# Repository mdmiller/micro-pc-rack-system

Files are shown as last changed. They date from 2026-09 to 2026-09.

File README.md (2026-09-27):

# Micro-PC rack system

3D-printable 19" rack mounting for 1-litre micro PCs. The current design is a 1U
shelf holding two machines side by side, front-loading, with keystone jacks for
console video at the front and a bay for the power bricks at the rear of each tray.

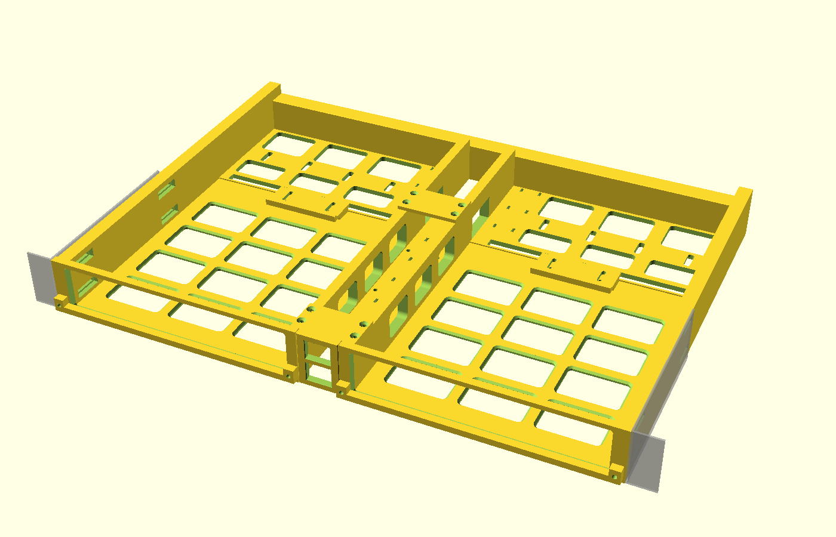
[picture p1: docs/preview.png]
Assembled shelf


**Status:** v3.1 plus the review fixes logged in [DECISIONS.md](docs/DECISIONS.md) (D21–D31),
verified in CAD. Nothing printed yet.

## What it has to do

The requirements the design has to meet. [docs/DECISIONS.md](docs/DECISIONS.md)
explains how each one shaped it.

1. Two 1L micro PCs in 1U of a 19" rack, lying flat, fronts facing out.
2. Mixed models: currently one Lenovo Tiny (179 × 183 × 34.5 mm) and one Dell
   OptiPlex 7060 Micro (182 × 178 × 36 mm).
3. Front keystone jacks for DP/HDMI pass-through — console access without reaching
   behind the rack. Video only; networking comes in from the rear (usually SFP).
4. Each machine removable from the front without disturbing the other.
5. A rear stop to locate each machine.
6. Power bricks and cord management on the shelf itself.
7. Metal, not plastic, in the rack-mounting load path.
8. Front-rail mounting only — no dependence on rear rails. That covers 2-post and
   wall-mount racks, and 4-post racks where the rear is taken up by cabling.
9. Modular toward a future 2U shelf for Minisforum MS-01s, sharing parts.

## Layout

```
cad/rack_1u_micro.scad   parametric OpenSCAD source — the single source of truth
stl/                     binary STLs, pre-oriented for printing; regenerate with build.sh
build.sh                 renders every part from the source
tests/run.sh             interference, clearance and alignment checks
tools/canon_stl.py       makes STL output stable, so git diffs mean real changes
docs/BUILD.md            parts, bill of materials, assembly, servicing
docs/DECISIONS.md        why the design is the way it is
docs/prior-art.md        survey of public designs and what was learned from them
```

## Working on it

```
bash build.sh                                    # all parts
openscad -o stl/tray_left.stl -D 'part="tray_left"' cad/rack_1u_micro.scad
```

Change dimensions in the source, not in the STLs. `build.sh` writes STLs in a canonical
triangle order, so rebuilding unchanged geometry leaves git clean — an STL diff means
the shape really changed.

**OpenSCAD version: 2026.09.18** (a development snapshot). Different versions
tessellate curves differently, so everyone builds with the same one. `build.sh` warns if
yours differs. On macOS, `brew install --cask openscad@snapshot`; elsewhere, see
<https://openscad.org/downloads.html#snapshots>. Snapshots move daily, so don't
`brew upgrade` it on your own: moving the pin means changing `OPENSCAD_VERSION` in
`build.sh` and committing the rebuilt STLs together.

v1 to v3.1 were iterated in Claude Cowork before this repo had any git
history, so the first commit is v3.1 (tagged `v3.1`) and the earlier versions survive
only in [docs/DECISIONS.md](docs/DECISIONS.md). Development continues here with Claude
Code; later delivered designs get their own tags. **Run
`bash tests/run.sh` after changing any parameter** — it checks every part pair on
both sides for collisions, that each machine still slides out, that screw holes
still line up, and that each part prints in its exported orientation with no overhang
beyond the known bridges and the features listed as needing support.

Questions and test-fit results are best as GitHub issues, one per topic, with photos
where relevant.

## Open items

- [ ] Caliper-check the steel bracket before printing both trays: the 23.8 mm hole-row
      spacing (`brk_row_dz`), and the bend-to-first-hole distance, which was never on the
      drawing (`ear_c0` assumes ~15 mm; the ±8 mm slots absorb small errors).
- [ ] Print one tray first and test-fit both machines.
- [ ] Watch temperatures for the first few weeks — see the thermal note in
      DECISIONS.md.
- [ ] Choose a keystone coupler per machine: slim-head HDMI or mini-DP (standard-head
      plugs don't fit; see BUILD.md and D26).
- [ ] Measure each machine's rubber-foot positions, so the floor vents can leave solid
      runners under them (#15).
- [ ] Get the MS-01 power adapter dimensions, then design the 2U shelf.

## Licence

© 2026 Matt Miller and contributors. Everything in this repo — CAD source, STLs,
scripts and docs — is licensed under
[CC BY-NC-SA 4.0](https://creativecommons.org/licenses/by-nc-sa/4.0/); full text in
[LICENSE](LICENSE). In short: print it, use it and remix it freely, as long as you
credit this project, don't use it commercially (that includes selling prints), and
share your remixes under the same licence. For anything commercial, open an issue
and ask.

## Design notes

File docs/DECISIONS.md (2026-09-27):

# Decision log

How the design got to where it is. Most entries follow the same shape: what was
decided, why, and what was rejected. Dates are when the decision was made.

v2 predates the power-brick requirement; v3 incorporates it. Mistakes made along
the way are noted where they happened and collected under Corrections at the end.

---

## Timeline

| Date | Event |
|---|---|
| 2026-09-19 | Brief: 1U shelf, two micro PCs, front keystone for video. v1 drafted internally and rejected; v2 delivered. |
| 2026-09-19 | Mixed Lenovo + Dell confirmed. Survey of public designs. |
| 2026-09-20 | Structural analysis, print orientation, steel ears, front serviceability. Power bricks raised as a hard requirement. Front-rail-only mounting set as a constraint. MS-01 modularity raised. |
| 2026-09-20 | Steel bracket drawing received; v3 designed, verified and shared. |
| 2026-09-20 | Second prior-art pass; the closest public design examined in detail. |
| 2026-09-21 | Repo created. Verification found four defects in v3's front lip; fixed in v3.1 and a test suite added. |
| 2026-09-21 | First git commit, at v3.1. Everything up to here was iterated in Claude Cowork sessions; from this point the work continues in Claude Code, with history in git. |
| 2026-09-21 | Independent review of v3.1 (Temple Keller). Brick bay inner tab found floating (D21); ear nut channels found impossible to load (D22); rear stop redesigned and a cable floor added (D23); fastener lengths, keystone clearance and assembly order corrected (D24). |
| 2026-09-21 | OpenSCAD pinned to 2026.09.18 (D25). |
| 2026-09-21 | Rear video plug clearance: slim HDMI or mini-DP, flange relief, cable floor moved back (D26). |
| 2026-09-21 | Keystone panel and brick bay tabs braced (D27). |
| 2026-09-21 | Rack opening measured at 450.85 mm; keystone column narrowed to 33 mm (D28). |
| 2026-09-22 | Ear bolts: square nut, no washer (D29). |
| 2026-09-22 | Printability fixes from the H2D review (D30). |
| 2026-09-22 | Tests check each part for unsupported overhangs in print orientation (D31). |
| 2026-09-22 | Docs cleanup: stale statements corrected, preview re-rendered. |
| 2026-09-25 | Both bricks calipered, smaller than D15 assumed in every axis; strap row moved so it holds them (D33). |
| 2026-09-23 | Rear stop reaches the Dell, stiffer front lip, chamfered floor vents (D32). |
| 2026-09-26 | Tray and brick bay print as one part, with a glued rear beam across both; centre sag from ~11 mm to ~2.9 (D34). |

---

## Geometry and fit

### D1 — Split the 19" shelf into printable parts
A 482.6 mm panel doesn't fit any consumer bed. Two trays joined at a centre keystone
module. v1 put an 8 mm screw boss across the seam, pushing each tray to 219 mm —
too close to a 220 mm bed — and was rejected before delivery. v2 moved to a top flange
screwed into the inner walls (215 mm trays). v3 is 201 mm (203 in v3.1), because the steel ears
(D8) remove the printed ear entirely.
*Since D34 each tray includes its brick bay and is 211 × 316 mm; the 220 mm bed goal is dropped.*

### D2 — PC faces flush in full-width openings
Each bay's front opening is the full bay width, so power buttons, front USB and jacks
are all reachable. **Correction:** v2's notes claimed the case front butted against
the panel. It doesn't — an interference test showed the pull-out corridor is clear,
so v2 had no front stop at all. That turned out to make front loading (D11) almost free.

### D3 — Mixed machines share one envelope
Bays are sized for the larger of the two in every axis (182 × 183 × 36). Only the
rear stop varies by model (a 34.5 mm Lenovo variant existed until D23 made one stop fit all). Do **not** re-render a
tray with a different `dev_h` or `dev_d`: `dev_h` sets the inner wall height the
keystone flange and tie plate sit on, and `dev_d` moves the tie-plate screws. `dev_w`
per tray is safe, at the cost of a 2 mm asymmetry in the front frame.

### D4 — Keystones are video only; stacked vertically
Two jacks, one per machine, for DP/HDMI couplers. Networking stays at the rear.
In v3 the jacks are rotated 90° and stacked: the thicker outer walls (D9) cost 12 mm
of width that had to come from the centre column, and side-by-side jacks would have
left 2.6 mm edges. Stacked needs ~29 mm; the column is 40 in v3, 36 in v3.1 (D19) and 33 after D28. Rear-plug clearance for this layout: D26.

---

## Structure

### D5 — PETG / ASA, not PLA
The concern is creep in a warm rack over months, not strength (see D6).

### D6 — The cantilever is not the problem; the ear screws are
Front-rail-only mounting with the bricks at the far end looked like the worst case,
so it was calculated rather than guessed. Per tray: PC 1.30 kg at 97 mm, brick
0.55 kg at 285 mm, structure 0.50 kg at 150 mm.

| Quantity | Result |
|---|---|
| Root bending stress | 0.73 MPa (≈3.6% of PETG layer-bond strength) |
| Tip deflection, short term | 0.18 mm |
| Tip deflection, creep-adjusted (E = 900 MPa) | 0.40 mm |
| Load per top rack screw, 1U ear | 111 N (11 kg) |
| Same, with a 2U-tall ear | 39 N |

The tray is a 39 mm-deep U-channel; depth beats length. **Correction:** an earlier
note had overstated the cantilever risk. The real concentration is the rack screw
pulling through a 5 mm strip of plastic beside a 7.2 mm slot, in the layer-weak
direction.

### D7 — Print orientation: floor-down, not face-down
Several public designs print face-down so the ear's bending stress runs along the
extrusions instead of across layer bonds (critical section ≈95 mm² of pure layer
adhesion when printed floor-down). That's correct for printed ears — but with steel
ears (D8) the printed part has no such critical section, and face-down would mean a
206 mm-tall print standing on a mostly-open front frame. So: floor-down, which is the
easier print.

### D8 — Steel rack ears
Penn-Elcom R1206/1U or equivalent: 1.5 mm steel, 43.8 × 20 mm leg, 139.4 mm web.
From the drawing: four Ø4.8 holes, columns 110 mm apart, rows 23.8 mm apart, lower
row 9.4 mm above the bottom edge (9.4 + 23.8 + 10.6 = 43.8, which is how the reading
was confirmed). Removes plastic from the load path and resolves D7.

### D9 — Continuous nut channels, not holes or inserts
The drawing doesn't give the bend-to-first-hole distance, so fixed holes risked
missing. Heat-set inserts can't be slotted, and there's no room inside the bay for
loose nuts. Each outer wall instead carries two M4 nut channels running front to back.
Consequences: outer wall 11 mm; M4 × 8 **button head** (a longer bolt bottoms out,
a socket head fouls the rail); body 442 mm, leaving 2.5 mm per side in a 450 mm
opening. **Correction (D28):** that counted the steel but not the bolt heads. Verified: an M4 hex nut seats in the channel and the bolt clears.
**Superseded by D22:** the nuts could never be loaded into the channels.

### D10 — Centre tie at front and rear
Keystone module (front) and tie plate (rear) both bolt across the two inner walls.
*D34 adds a rear beam glued in across both trays.*
Field evidence later confirmed this matters: users of the closest public design found
it needs support in the centre once racked (see prior-art.md).

---

## Serviceability and retention

### D11 — Front loading
In a tightly packed rack, pulling the whole shelf to service one machine is not
acceptable. Since the corridor was already clear (D2), v3 only needed a front stop.

**Servicing procedure (2026-09-21, issue #7):** a machine's rear cables are unplugged
from behind the rack before it slides out the front. Pulling it out with cables still
attached would need ~200 mm of free slack on each rear cable. Behind each machine, the
bay has only ~8–27 mm of free depth left after the rear plugs and the brick, and
building in room for service loops would lengthen the shelf. The machines have no
hot-swappable parts, so a rare, tight reach from behind was judged the simpler
trade-off.

### D12 — Front lip instead of clips
Per-bay clips were planned, but there's no structural material inside the full-width
opening to anchor them. The lip spans the opening and screws into the two wall strips
either side, covering the bottom 5 mm of each case front (bezel on both models).
Two screws, lip off, machine slides out. Redesigned in v3.1 after defects were found (D19).

### D13 — Rear stop is set once
Slotted for ±7 mm (172–186 mm device depth), with a 45° self-supporting hook over the
case's rear top edge to stop lift. It's positioned at build time, not a service item.
**Hook replaced by a low curb in D23.**
*The ±7 mm / 172–186 mm figures were stale; the stop reached 179.5–190.5 mm, which missed
the 178 mm Dell. Moved in D32 to 175.5–186.5 mm.*

---

## Power bricks

### D14 — Bricks on the same shelf, behind the PCs
Not a separate U: the point of the design is density, and a U spent on power bricks
is a U lost. The shelf mounts on the front rails only (requirement 8), so it grows
rearward in a bolt-on bay (part of the tray since D34) rather than reaching for rear rails. D6 showed the extra
moment is harmless. On a 4-post rack, rear support is an available fallback, but
nothing in the design needs it.

### D15 — Bricks crosswise
Designed to the Lenovo brick (112 × 51 × 35 mm plus ~70 mm of plug and boot) and the
Dell 90 W (130 × 70 × 28). A 130 W Dell adapter exists but isn't needed. Laid crosswise
with mains ends outboard, the pair uses ~372 mm of the width and a 90 mm-deep bay;
lengthwise would have needed ~190 mm of depth. Overall depth ~316 mm. The Lenovo's
35 mm thickness leaves 6.5 mm of headroom in the U, so straps pass under and around,
never over. DC leads run forward through the 36 mm centre gap between the two bays.
*Corrected since: the bay floor is 4 mm, so headroom is ~5.5 mm, and a strap does pass
over the brick (D24). DC leads only run forward to each machine's own jack; the centre
gap carries the video leads (D23). Both bricks were calipered on 2026-09-25 and are
smaller in every axis: Lenovo 65 W slim 107 × 46 × 29, Dell 90 W 128 × 66 × 23. Headroom
over the Lenovo is ~11 mm, not ~5.5, and the pair uses ~365 mm of width (D33).*

### D16 — Thermal risk, accepted and partly de-risked
Both machines exhaust rearward toward the bricks. Mitigations: ~29 mm plenum, vented
floor, open rear, and bays that unbolt so the bricks can move to their own U without
touching anything else (*no longer: the bays are part of the trays, D34*). Later evidence: the closest public design puts two PCs and
both bricks in 1U with the bricks directly behind, printed in PLA+, and months of
use by several builders produced no heat or warping complaints. Still worth watching.
*The plenum is now ~40 mm: the bricks sit behind the 25 mm kept clear for the machines'
rear plugs.*

Design assumptions: machines that run mostly idle rather than at sustained full
load, in a rack with its own forced ventilation and an interior at or below about
40 °C (100 °F). Under those assumptions, going to 2U for thermal reasons was rejected
as a waste of rack space, and the shelf has no fan of its own. If your rack is
hotter, unventilated, or the machines run flat out, revisit this: the open rear
leaves room to add a fan.

---

## Scope and ecosystem

### D17 — 1U micro shelf now; 2U MS-01 shelf later, sharing parts
The MS-01 is 196 × 189 × 48 mm with a 180 W adapter. At 48 mm it cannot fit in 1U,
so it gets a 2U shelf that reuses the ears, keystone module, brick bays and rear
stops. Only the tray changes.

### D18 — Build our own rather than remix the closest public design
Nothing public met all the requirements (see prior-art.md). The closest is
Turaj Pilehvar's Dell Micro 1U mount. Remixing was rejected because: it is STL-only
and the author has confirmed no CAD exists; another user tried importing the STLs
into Fusion 360 for a remix and gave up to redraw from scratch; and changing the bay
for a Lenovo plus adding keystones would alter exactly the geometry that had been
field-tested. What transferred instead was information (D10, D16).

### D20 — Licence: CC BY-NC-SA 4.0 (2026-09-21)
The goal: anyone can print, use and remix the design, with attribution, but not
commercially. CC BY-NC-SA 4.0 does that, and ShareAlike keeps remixes under the same
terms. One licence covers the whole repo, scripts included — Creative Commons advises
against CC licences for software, but the scripts here are small helpers tied to the
design, and splitting licences wasn't worth the complexity. CC BY-NC (no ShareAlike)
was the alternative considered. The `CC-BY-4.0` note in the v3 source header was
added during drafting without anyone deciding it, and is replaced.

---

## Corrections

### D19 — v3.1: front lip defects, found in verification (2026-09-21)
Found while setting up this repo, not by printing. Chasing zero-area triangles in
the exported front lip led to four real defects in v3 as shipped:

1. **The right-hand lip didn't line up.** The lip's holes weren't symmetric, but the
   same part was placed on both trays without mirroring. On the right tray the holes
   missed the pilots by 2.5 mm. The v3 checks only ever tested the left side.
2. **The inner hole broke out of the lip's end** — its centre sat 1 mm from the edge.
3. **The countersunk head was wider than the lip:** a 6.6 mm head on a 5 mm strip,
   leaving 0.8 mm of plastic around the hole.
4. **The outer pilot ran ~1 mm into the lower nut channel.** Two voids touching,
   which no solid-against-solid test can see.

Fixes:
- Symmetric lip with 11 mm end tabs sitting over the two wall strips (never over a
  PC face), M3 pan heads instead of countersunk. One part fits either tray.
- Outer pilot shortened to stop 1 mm short of the nut channel.
- Inner walls widened 6 → 8 mm, taken from the keystone column (40 → 36; the stacked
  jacks need ~29). Overall width unchanged at 442 mm. Every screw into the inner
  walls — keystone flange, tie plate, lip, brick bay — now gets 4 mm of edge
  distance instead of 3, and no countersink breaks out of a flange edge.
- Countersink cones everywhere now stop at the clearance diameter rather than a
  zero-width point.

The checks that would have caught all four are now in `tests/run.sh`: every part
pair on both sides, rods down each lip hole *as placed*, void-against-void tests,
and nut and bolt fit. The alignment tests were confirmed to fail both on the
shipped v3 and on a deliberately broken lip.

**The v3 files shared before this repo existed have these defects. Use this repo.**

### D21 — Brick bay inner mounting tab floated above the floor (2026-09-21)
*The tabs are gone since D34.*
Found by counting connected solids in the exported mesh: `brick_bay` was two
separate bodies. Both front mounting tabs started at z = 8. The outer one overlaps
the outer lip beneath it (12 mm tall), so it was fused. The inner edge is the open
cable-run side and has no lip, so the inner tab hung 4 mm above the 4 mm floor with
nothing joining them. It sliced as an unsupported island, and it carries one of the
two bolts that hold each bay to its tray.

Fix: both tabs now run from the floor (z 0–32). The outer tab is unchanged in the
union, because it already sat inside the lip.

Why the checks missed it: every existing test is an intersection between two parts,
and a part that falls apart into two bodies doesn't collide with anything. New test
`bb_tab_rooted_L` requires the space under the inner tab to be solid; it fails on
v3.1 and passes now.

### D22 — Ear nut channels couldn't be loaded; replaced with per-bolt pockets (2026-09-21)
*Washer and hex nut replaced by a square nut in D29.*
D9's channels were sealed at both ends. They run y 8–165 inside a wall that runs
6–206, so the "slide the nuts in from the rear" step had 41 mm of solid wall in the way.
The only opening was the 4.8 mm bolt slot on the outside face. A 7 mm nut passes that
only lying flat, and the 4 mm-deep pocket has no room to stand it up. Sweeping the
`m4_nut_fits` nut out of its seat towards the bay, the outside, the rear and the front
hits wall every time. Each channel roof was also a 157 mm unsupported bridge when
printed floor-down.

Fix: four pockets per tray, one per bracket hole, each open to the bay. A washer and
nut go in from inside before the machine does; the bolt comes in from outside through
a slot that keeps ±8 mm of fore-aft travel (`ear_c0`, `ear_travel`), so the
bracket's column position still needn't be exact. The longest roof is now a 25.6 mm
bridge supported at both ends.

- **Washer:** it spreads the clamp load off the strips of skin beside the slot. The
  old nut bore on two 1.1 mm strips.
- **No anti-rotation:** a stepped pocket that would stop the nut spinning was tried and
  dropped. A 9 mm washer can't pass a 7.3 mm nut opening or be turned upright inside
  one, so the pocket is washer-sized and the nut is held while tightening.
- **Bolts:** now M4 × 12. Through 1.5 mm steel, 6.5 mm skin and a 0.8 mm washer, the
  tip lands flush with the nut face, 0.5 mm short of the bay.
- **Lip pilot:** the outer lip pilot keeps D19's rule and stops 1 mm short of the new
  front pockets.

Why the checks missed it: `m4_nut_fits` placed a nut in its final position and
confirmed it fit. It never asked how the nut got there. Replaced by:
- `m4_hw_seated`: bolt, washer and nut at both ends of travel in all four holes.
- `m4_hw_insertable`: washer and nut swept in from the bay.
- `m4_past_travel`: the same hardware 4 mm past the end of travel must hit wall, which
  proves the other two can fail.

### D23 — Open rear, cable floor, zip-tie anchors (2026-09-21)
**Rear stop.** The hook's web was a solid plate 64 mm wide and 33 mm tall, flush
against the middle third of each machine's rear face (about 32% of it), where the
ports and exhaust are. That conflicts with requirement 3's rear video cables and with
D16's airflow, and it depended on `dev_h`, hence the Lenovo variant. The stop is now
a curb that touches only the bottom `stop_h` (8 mm) of the rear face. One part fits
every machine, the rear stays open for any port layout, and the Lenovo variant is
gone. It gives up the hook's lift restraint; the U above and the front lip bound that.

**Cable floor.** Requirement 6 calls cord management imperative, but the video leads
had no supported route to the keystones:
- the inner wall behind each machine is solid;
- the tie plate leaves ~2.5 mm over the top of the wall;
- the centre channel between the trays had nothing under it.

A new `cable_floor` part spans the channel on a 6 × 4 mm ledge added to each inner
wall and screws down from above. Zip ties pass through slot pairs into the 4 mm gap
beneath, so nothing hangs below the shelf. It also ties the bottoms of the two trays
together; that stiffening hasn't been quantified. The route for each video lead is:
machine's rear → brick bay → centre gap → cable floor → keystone. D15's "DC leads run
forward through the centre gap" was a slip: DC leads only go forward to each
machine's own jack.

**Brick bay.** Zip-tie anchors along the inboard edge: slot pairs joined by an
underside groove, so the strap sits flush with the bottom face.

New tests:
- `tray_cf`, `keystone_cf`, `tie_cf`, `bricks_cf`: no collisions.
- `cf_holes`: screw cores pass the floor into the ledge pilots without bottoming out.
- `ziptie_void`: the gap under the floor is clear.
- `rear_face_open_L`: nothing touches the rear face above the curb.
- `stop_meets_face_L`: the curb does meet the face.

### D24 — Fastener lengths, keystone clearance, assembly order, supports (2026-09-21)
Found by working through every screw (reach, length, engagement), every assembly step
(possible in this order, in a rack?) and every part (printable as exported?):

- **Rear-stop screws broke through.** The BOM's M3 × 10, through the 3 mm foot into
  6 mm of pad and floor, stuck 1 mm out of the underside into the U below. Now M3 × 8,
  and the pilot starts at z = 0.6 so the flat tip clears the pilot bottom instead of
  meeting it. The test models the screw 0.5 mm long to keep that margin, which catches
  both the old pilot and the old screw.
- **The keystone panel had zero clearance:** 36.0 mm in a 36.0 mm gap between the tray
  panels. Now 35.4 mm (`ks_clr` = 0.3 per side, the same as the cable floor).
- **Assembly order.** Tightening the ear bolts and setting the rear stops after racking
  isn't possible with the U above populated: the nuts and stop screws are reached from
  above, and the bolt heads sit between the bracket and the rail. All of that, plus
  fitting the couplers and plugging in the video leads, now happens on the bench. The
  couplers go in first, with the panel backed up, because the installed panel hangs
  from a 36 × 3 mm joint loaded across the print layers. The shelf is racked empty and
  the machines slide in from the front.
- **Supports.** The strip above each PC opening is a 184 mm unsupported span when
  printed floor-down, so the trays need supports there. "No supports" was wrong.
  *Since then (D31, 2026-09-22): slicer settings, including how to support, are left to
  the 3MF built from this geometry. BUILD.md only says which features need support, and
  `tests/run.sh` checks that list. "Supports from the build plate are enough" was wrong:
  the support stands on the panel's own lower strip.*
- **Headroom.** The bay floor is 4 mm, not 3, so the Lenovo brick gets about 5.5 mm of
  headroom, not 6.5. A velcro strap does pass over the brick: it has to, to hold it.
  That corrects D15.
  *Since measured (D33): the Lenovo brick is 29 mm thick, so headroom is ~11 mm.*

New tests:
- `stop_screws_L` / `_R`: fail on v3.1, pass now.
- `keystone_side_clear`: fails on v3.1 with 131 mm³ of overlap, passes now.
- `cf_holes`: now uses 2.6 mm cores, so a tip that runs through a pilot's skin shows up
  above the 2 mm³ threshold.

### D25 — Pin the OpenSCAD version (2026-09-21)
Different OpenSCAD versions tessellate curves differently. `canon_stl.py` only makes
identical *triangles* byte-identical, so two contributors on different versions each
rewrite every curved STL on every build. The review PRs (D21–D24) were built on
2026.06.12, and three STLs then changed when rebuilt on 2026.09.18, with no change in
shape. Pinned to 2026.09.18, the version the owner already had and the current
Homebrew `openscad@snapshot`. `build.sh` warns on a mismatch rather than failing,
because a mismatched build is still geometrically correct, just noisy in git. The
2021.01 stable release was never in use here.

### D26 — Rear video plug clearance (2026-09-21, issue #6)
The rotated, stacked jacks (D4) put each rear plug on its long edge, 18.8 mm apart,
between the keystone flange above (underside at z = 39, back to y = 36) and the
cable floor below. Plugs were modelled as blocks at two coupler depths (rear face 24
and 32 mm behind the panel front):

- **Standard HDMI or DP heads (~21 × 11 × 40 mm)** collide with each other, the
  flange and the cable floor under every small change considered. The two plugs alone
  overlap by ~1000 mm³.
- **Slim HDMI heads (16 × 6.6 × 14 mm)** missed by ~0.2 mm per side at the flange and
  hit the cable floor at the deeper coupler depth.
- **Mini-DP** is smaller still.

Three ways to make 2 × slim HDMI fit were compared:

| Option | Upper plug to flange | Plug to plug | Cost |
|---|---|---|---|
| `ks_gap` 4 → 3 | 0.3 mm | 1.8 mm | halves the full-thickness plastic between the jacks (2 → 1 mm) |
| **1 mm relief in the flange underside** | 0.8 mm | 2.8 mm | flange 2 mm thick instead of 3 over a 9 mm-wide strip |
| Move the flange back | — | — | restructures the keystone module for no extra gain |

Chosen: the relief (`ks_relief_d` = 1.0, `ks_relief_w` = 9). It starts behind the
panel at y = 8.8, so the panel-to-flange joint is untouched. `cf_y0` goes from 44 to 50
so the lower plug's head clears the floor. The first cable-floor screw pair moves
54 → 58 to keep its edge distance.

**Supported cables:**
- 2 × slim HDMI (passive; active RedMere cables may not like a passive coupler);
- 2 × mini-DP;
- one of each;
- mini-DP upper with standard HDMI lower, provided `cf_y0` goes to ~85–90.

Standard-head cables in both jacks would need the jacks turned upright and the flange
cut away over them. That's a different layout, not taken.

Tests: `plug_vs_keystone`, `plug_vs_cf` and `plug_vs_plug` check both jacks at both
coupler depths. The first two failed before this change. `flange_over_relief` checks
that 2 mm of flange remains.

### D27 — Brace the keystone panel and the brick bay tabs (2026-09-21, issue #11)
*The brick bay tabs and their braces are gone since D34.*
Two parts behave like vertical posts loaded across their print layers. The numbers
are hand calculations with rounded loads; the ratios are what matter.

**Keystone panel.** It hangs from a 35.4 × 3 mm joint with the flange. The module
prints panel-down, so that joint is a layer boundary. A 30 N push on the lower jack,
from plugging a monitor into the front, gives ~16 MPa there, repeated at every plug-in.
Two 12 mm braces between the panel back and the flange underside fix it. They sit in
the 3.7 mm strips at the panel edges, clear of the jacks' latch travel. The composite
section takes the same push to ~2.2 MPa, about 7× less, and the braces print as 45°
fins.

**Brick bay tabs.** The bay hangs from two bolts at z = 20.
- **Inner tab (8 × 4 mm).** At rest it sees ~6.5 MPa at its root; a 50 N handling load
  gives ~38 MPa. An 11 mm brace behind it, topping out below the bolt head, moves the
  weakest section up to the brace top, where the same load gives ~12 MPa.
- **Outer tab (above the 12 mm lip).** A 50 N load gives ~14 MPa; a 4.5 mm brace takes
  it to ~6 MPa.

The bay braces sit in the front ~25 mm that is already kept clear for the machines'
rear plugs.

**Not braced:**
- the tray wall-to-floor corners inside the bays (~1 mm PC clearance, no room);
- the tray's front posts (backed by the full-length walls).

Tests: `ks_braces_present` and `bb_braces_present_L` fail before this change and pass
now. `ks_latch_room` keeps the jacks plus 2.5 mm of latch travel clear; widening the
braces to 6 mm makes it fail. `bb_driver_clear_L` keeps the M3 heads and the screwdriver
path along y clear.

### D28 — Clearance in the rack opening (2026-09-21, issue #5)
With the steel ears fitted, the shelf is widest across the M4 button heads: body
+ 2 × 1.5 mm web + 2 × 2.2 mm head. At 442 mm that was 449.4 mm. The rack's clear width
between the front rails was measured at 450.85 mm (17¾", two tapes), leaving 0.7 mm
per side. That's about a tape measure's own accuracy, before print tolerance or web
flatness. Standard rack equipment leaves about 3 mm per side.

Four ways to take 3 mm out were run against the full test suite:

| Change | Result |
|---|---|
| **Keystone column 36 → 33** | all checks pass |
| Column 34, bay fit 1 → 0.75 | machines graze the openings sliding out (`pullout`) |
| Inner walls 8 → 7, bay fit 0.75 | `pullout` and `lip_clear_of_face` fail |
| Column 34, inner walls 7.5 | `lip_clear_of_face` fails |

Chosen: `key_w` = 33, giving a 439 mm body, 446.4 mm across the bolt heads and
**2.2 mm per side**. The keystone panel, tie plate and cable floor are all derived from
`key_w` and follow. The cost is latch access: the gap between each keystone brace (D27)
and the jack body shrinks from ~4.3 to ~2.85 mm. That still covers the 2.5 mm of latch
travel `ks_latch_room` reserves, and couplers are fitted once on the bench. 33 is the
floor: at 32 the braces cut into the latch clearance.

`rack_open` and `rack_margin` now live in the source. The new test
`rack_width_margin` models the heads at every bolt and fails if they come within
2 mm of the rails; it fails at 36 (461 mm³ outside the margin) and passes at 33.

### D29 — Ear bolts: square nut, no washer (2026-09-22, issue #15)
D22's pocket was sized for a 9 mm washer, which made it taller than the hex nut's
8.1 mm corners. That caused two problems:
- The nut spun freely. The only way to hold it was a fingertip; a spanner can't get
  around a nut inside a 9.3 mm pocket.
- The pocket had 0.3 mm of clearance over the washer. Layer quantisation and roof sag
  (#15) could close that up, so the washer might not go in at all.

A square nut in the same washer pocket doesn't fully fix it. Its 9.9 mm diagonal lets
it turn 23–37° before jamming corner-first into printed plastic, depending on the
printed pocket height. And the window between "washer won't fit" and "nut spins
freely" is only ~0.7 mm.

Chosen: **square M4 nut (DIN 557), no washer, pocket sized to the nut** (7.4 mm tall,
`nut_clr` 0.4). In that pocket the nut can turn about 2.5° before it locks, and it
still slides fore-aft with the ±8 mm travel.

**What dropping the washer costs.** Once the 4.5 mm slot band is taken out, the nut's
face bears on less plastic:

| Nut bearing on plastic | Area | Stress at ~0.5 N·m |
|---|---|---|
| washer (D22) | ~25 mm² | — |
| **square nut** | **~17.5 mm²** | ~36 MPa |
| hex nut | ~11.9 mm² | ~52 MPa |

Among the no-washer options the square nut is clearly better: the hex nut is already
around PETG's crush strength at snug. Dropping the washer also frees 0.8 mm, so the
solid skin goes from 6.5 to 7.3 mm, which helps pull-through and the slot edges' bearing
against the bolt. M4 × 12 still lands flush with the nut face, 0.5 mm short of the bay.

**Assembly note.** BUILD.md now says "snug, not hard". The joint's load is the bolt
shanks bearing on the slot edges, not clamp force.

Test: `m4_nut_cannot_spin` requires the nut's full turning circle to hit wall at every
seat. It gets 427 mm³ here. With the washer-height pocket it's 50 mm³, so that pocket
would let the nut turn. The seated, insertable and past-travel checks now use the
square nut. D22 marked partly superseded.

### D30 — Printability fixes from the H2D review (2026-09-22, issue #15)
Model changes from #15 that don't depend on a test print:

- **Cable-floor ledges 6 → 8 mm.** The M3 pilot, centred in a 6 mm ledge, left
  1.65 mm of plastic on the inboard side, likely to split as the screw self-taps. Now
  2.65 mm each side. The void between the ledges drops to 17 mm, so the zip-tie slot
  pairs move from ±8 to ±6 mm about the centre; `ziptie_void` still passes.
- **Plenum and velcro slots no longer touch.** The plenum slot (y 2–10) and the front
  velcro slots (then y 10–26) met at y = 10, the same "two voids touching" defect as
  D19. That left the bay's front edge as two thin ribs, and it's the edge that bears
  on the tray. The front velcro row moves to y = 20.5, leaving 2.5 mm of rib to the
  plenum and 2.5 mm to the vent grid. *Since replaced by a single row at y = 48 (D33).*
- **Velcro strap path recessed.** The zip-tie anchors got underside grooves in D23;
  the velcro slots didn't, so a strap under the floor stood ~1.5–2 mm below the shelf
  into the inter-U gap. Each slot pair is now joined by a 16 × 2 mm underside groove.
  Printed floor-down, that's a 16 mm bridge.
- **Keystone panel chamfer and clearance.** The panel prints face-down, and first-layer
  flare (0.1–0.25 mm per side) ate most of the 0.3 mm side clearance and narrowed the
  aperture fronts where the couplers enter. A 0.5 mm 45° chamfer round the face-down
  perimeter and both apertures (`ks_chamfer`) removes the flare, and `ks_clr` goes
  0.3 → 0.5. The braces (D27) move in with the panel edge and still clear the latch
  zone.

**Waiting on data:**
- **Horizontal pilot size (2.7 → 2.9 or teardrop):** waits for a test print.
- **Solid runners in the floor vents under the machines' feet:** waits for the actual
  foot positions.

New tests: `bb_plenum_velcro_rib`, `velcro_groove_clear` and `ks_face_chamfered` all
fail on the previous geometry and pass now.

### D31 — Test for unsupported overhangs in print orientation (2026-09-22, issue #15)
#15's point 8: every check in `tests/run.sh` was solid-against-solid in the
assembly, so nothing could see how a part prints. That's how the keystone flange
wings, which start 6 mm above the bed with nothing under them, reached `main`. It's
also how v3's floating brick-bay tab (D21) got through until someone counted shells.

**The check.** Each part is taken in its exported orientation. A new `printed(p)`
module holds the export transforms, shared by `build.sh` and the tests; the refactor
leaves every STL byte-identical. The part is sliced every 0.4 mm, and material not
within 45° of the slice below counts as unsupported. An opening of 1.3 mm removes
slivers narrower than 2.6 mm: these are the caps of M3/M4 horizontal holes and
countersinks, which bridge trivially. What remains must fall inside that part's
**allow-list**:

| Part | Allowed | Why |
|---|---|---|
| trays | strip above each PC opening | **needs support** |
| trays | ear-bolt pocket and slot roofs, inner-wall vent roofs | bridges ≤ 30 mm |
| keystone | the two flange wings | **needs support** |
| brick bay | velcro and zip-tie groove roofs under the floor | bridges ≤ 16 mm |
| all others | nothing | |

So a new overhang fails unless someone decides it's a bridge or that it needs support,
and adds it to the list. The allow-list boxes are derived from the same parameters as the features,
so they move with the geometry.

**Controls.**
- `ov_control_wings` runs the keystone with no allow-list and must catch the wings
  (227 mm³).
- Restoring v3.1's floating tab in a scratch copy makes `ov_brick_bay` fail at exactly
  the tab (x 195–203, z 8).

**Scope.** This is a geometry check: which features bridge and which need support.
How to support them is a slicer decision and lives in the 3MF, not the repo.

**Limits.** It judges geometry, not a slicer. The 45° rule and the 2.6 mm sliver
filter are approximations; bridge quality, sag and first-layer flare aren't modelled.
Adds ~2 s to the suite.

### D32 — Rear stop reach, stiffer front lip, chamfered floor vents (2026-09-23)
**Rear stop reach.** With the front lip fitted, a machine sits with its front face flush
with the panel front (y = 0), so the stop's face has to reach the machine's depth. Its
slots only covered 179.5–190.5 mm. The Lenovo (183) was fine, but the Dell 7060 Micro
(178) could never be set snug and kept ~1.5 mm of rattle. The tests missed it because
they modelled the machine 6 mm back, at the panel's rear face. Moving the stop's
pilots and pad 4 mm forward (`ret_y` = `tray_d` − 10) gives 175.5–186.5 mm, which
covers both with ≥ 2 mm margin.

The test machine envelope and the assembly now put the machine against the lip. New
parameter `dev_depths` lists the machines, and `stop_reaches_*` checks that an M3
through each pad pilot passes the stop's slot at every listed depth. At the old
position the Dell check fails (22 mm³).

**Stiffer front lip.** The lip was a 5 mm-tall, 3 mm-deep bar spanning ~194 mm between
its screws, and it felt flimsy in the hand on a test print. As a retainer it was
already adequate: a flat machine face bears near the lip's ends, where it's stiff,
about 0.1 mm per N. But it bent and twisted easily when handled. It's now 6 mm deep
(`lip_t`), about 8× stiffer in bending and far stiffer in torsion. Its height is
unchanged, so it covers no more of the machine's face. It stands 6 mm proud of the
panel instead of 3, and it still prints face-down.

The lip screws become M3 × 12. New checks `lip_screws_L/R` confirm they seat in the
tray pilots without bottoming out; M3 × 12 would have hit the pilot bottoms with the
old 3 mm lip.

**Chamfered floor vents.** A machine sliding in crosses four rows of vent openings on
its rubber feet. #15 flagged that a foot can drop in and catch on a square edge. Each
cell's top edge now has a 1.5 mm 45° chamfer (`vent_chamfer`), so a foot rides out.
This needs no foot positions. Solid runners under the feet remain an option once
the positions are measured. The 10 mm ribs keep a 7 mm flat top.
`vents_chamfered` checks every cell; with no chamfer it fails.

**Not changed:** the Lenovo's side play (179 mm in a 184 mm bay). Nobody has asked for
it tightened; D3 describes the per-tray `dev_w` route if that changes.

### D33 — Bricks calipered; one strap row, centred on them (2026-09-25)
**Measurements.** Both bricks were calipered. D15's figures were over in every axis:

| Brick | D15 | Calipered |
|---|---|---|
| Lenovo 65 W slim | 112 × 51 × 35 | **107 × 46 × 29** |
| Dell 90 W | 130 × 70 × 28 | **128 × 66 × 23** |

They're now in the source as `bricks`, so the tests can use them. Nothing in the bay
depended on the bricks being larger: `bb_depth` stays at 90 (66 is needed), and D6's
loads assumed heavier bricks than these. Two things do change:

- **Headroom.** 44.45 − 4 (bay floor) − 29 = ~11 mm over the Lenovo, not ~5.5. The
  "room for a strap over the top, nothing more" warning in BUILD.md and D24 goes.
- **The strap rows couldn't hold the Lenovo.** The slot rows at y = 20.5 and 93 (bands
  12.5–28.5 and 85–101) need a brick at least 59 mm deep to sit under both. With the
  brick's front edge 25 mm back, as BUILD.md asks, the front band overlapped the Lenovo
  by 3.5 mm and the rear band not at all; the Dell got 3.5 and 6 mm. A 16 mm strap with
  3.5 mm of brick under it slips off the edge. The measured widths (46, 66) made this
  worse, but the rows were already wrong at 51 and 70.

**Fix.** One slot row at y = 48 (`strap_y`), centred on the Lenovo's 25–71 and inside
the Dell's 25–91 with ≥ 15 mm to spare each side. Each brick gets two loops, through
the (30, 70) and (110, 150) slot pairs, each pair with its underside groove: four
straps, which is what the BOM always said. The row also locates the bricks: a strap
over the brick puts its front edge at `bb_clear` = 25, the plug clearance BUILD.md
used to ask for by hand.

The vent grid moves out of the strap band: a 22 mm row ahead of it (y 15–37) and a
38 mm row behind (59–97), still three cells wide (`vent_rows`). Open area per bay goes
from 5280 to 7200 mm², and no strap crosses a vent. The rib between the plenum slot and
the front vent row is 5 mm; between the plenum and the strap slots, 30.

**Not changed:** the slot pitch. For the Lenovo (x 12–119) the second loop's inner
slot at x = 110 sits 9 mm inside the brick's end, so that strap comes up under the
brick and over its end rather than beside it. It still cinches, and threading the straps
before the bricks go in was already the order in BUILD.md.

**Tests**, one per entry in `bricks`: `brick_in_bay_i` (the brick, front edge at
`bb_clear`, clears the bay's lips and the tray) and `strap_under_brick_i` (the 16 mm
strap band falls wholly inside the brick's footprint). At the old rows the Lenovo check
fails with 2538 mm³ (front row) and 3248 mm³ (rear row: the entire band); at y = 48
it's zero. The D30 velcro checks and the D31 overhang allow-list now read the strap
parameters instead of literals.

### D34 — One-piece trays and a glued rear beam (2026-09-26)
**Problem.** The shelf hangs from the ears on its outer walls. Only the trays' vented
3 mm floors hold up the middle. A grillage model of one half-shelf (machine, brick and
self-weight; tied at the keystone and tie plate; solid plastic, E = 2000 MPa) puts the
seam **11.4 mm** low, and **~25 mm** once the plastic creeps (E ≈ 900). Stress is only
~8 MPa, so the shortfall is stiffness, not strength. More tie plates at the front don't
help: the ties there are already rigid.

**Fix.** Each tray prints with its brick bay as one part, and one `rear_beam`
(417 × 16 × 33 mm) is glued in across the back of both:
- The floor and outer wall run the full 316 mm. The inner wall stops 16 mm short, and
  the beam sits in that strip: on the floors, between the outer walls, against the
  inner walls' ends, glued to all three. The bolted tray-to-bay joint and its tabs are gone.
- The beam is what does the work. Each inner wall carries most of the middle's load to
  the rear. The beam, continuous across the centre, holds those ends up and stops them
  tipping, and hands the load to the outer walls, which the ears hold. Two separate
  ribs would hinge at the seam. A tie plate on top of the walls can't prevent that,
  because nothing joins the walls at the bottom behind the cable floor.
- A 35 × 20 mm window in the inner wall behind the machine takes the video leads.

| Worst sag | Before | Separate 16 mm ribs | Continuous beam, 33 mm tall |
|---|---|---|---|
| Short-term | 11.4 mm | 4.2 mm | **2.9 mm** |
| After creep | ~25 mm | ~9 mm | **~6.5 mm** |

**Height.** The beam's top is level with the tallest brick, 33 mm (`rb_top`). The
machines exhaust rearward, and their rear cables and the mains cords come in over the
back (D16, D23). So the rear has to stay open above the beam: 11 mm to the U above,
where the bricks already leave that much. At the full 39 mm wall height the beam would
be ~10% stiffer (2.6 / 5.8 mm) but leave a 5 mm slot; at 24 mm it leaves 20 mm and
sags 3.8 / 8.5 mm. A 32 mm-deep beam would halve the sag, but it needs 16 mm more shelf
depth or less room for the bricks. The worst point is now the keystone.

The beam takes 8 mm from the bricks' side of the bay (`bb_depth` 90 → 82). The Dell
brick still has 3 mm behind it, and the rear vent row is now y 59–91.

**Printing the beam.** It prints top-down along the plate diagonal, ~8 mm clear of the
325 × 320 single-nozzle edges. Its top edges and the bottom of the centre section, which
drops into the gap between the trays, are chamfered 0.6 mm to keep elephant's foot on
either part out of the joints.

**Cost.** Each tray is 211 × 316 mm and needs a bed at least 320 mm on one axis (D1's
220 mm goal is dropped). Once glued, the shelf is one permanent unit, and the bays no
longer unbolt (D16). Filament rises by ~270 cm³.

**Tests.** The joint's checks go (`tray_bricks_*`, `bb_tab_rooted_L`,
`bb_braces_present_L`, `bb_driver_clear_L`, `ov_brick_bay`). New:
- `tray_rear_beam`: the beam clears the trays.
- `rear_beam_glue`, `rear_beam_on_floor` and `rear_beam_located`: it bears on the inner
  walls' ends, on the floors and on the outer walls.
- `rear_beam_span`: it runs unbroken across the centre.
- `rear_beam_fits_bed`: it fits the diagonal with 2 mm to spare.
- `ov_rear_beam`: no unsupported overhangs top-down.
- `tie_screws`: the tie plate's screws sit in their pilots.
- `bay_spine`: the inner wall over the window is present.
- `lead_window`: open.
- `rear_open`: nothing stands above the beam across the rear, between the outer walls.
- `brick_in_bay_i` now counts the beam as well as the tray.

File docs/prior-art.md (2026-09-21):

# Prior art

Public designs surveyed on 2026-09-19 and 2026-09-20, and what was taken from each.
None met all the requirements in the README.

## Closest overall — Turaj Pilehvar, "Dell Micro PC 1U Rack Mount"
https://www.printables.com/model/775243-dell-micro-pc-1u-rack-mount

Two Dell Micros and both power supplies in 1U, with cable management. The only free
design found that handles bricks at full two-machine density.

- **Layout:** PCs flat at the front with faces in the panel, power supplies directly
  behind them, printed cross-bars strapping both rows down, cable exit at the rear
  centre. Essentially the same architecture as ours, arrived at independently.
- **Material:** shown in PLA+.
- **Construction:** printed pins, then glued or friction-welded — the author and at
  least one builder found welding necessary for rigidity. Permanent; not serviceable.
- **Gaps for us:** Dell only, no keystone, printed ears, STL only (no CAD exists).
- **From the comments:** one user wanted a Lenovo Tiny remix; another tried to remix
  via Fusion 360, couldn't work with the STLs, and redrew from scratch; one asked for
  a front RJ45; one advised making sure the shelf is supported in the centre. No
  reports of heat, warping or sag across the whole thread.

## Others

| Design | What it does well | Why not for us |
|---|---|---|
| [PNW_PRNTR, Lenovo dual 1U](https://makerworld.com/en/models/923893-lenovo-thinkcentre-dual-1u-19-inch-rackmount) | Two Tinys, front keystone, slide in/out from the front with a rear stop | No brick handling, printed ears |
| [noamf, Dell Micro 1U](https://www.printables.com/model/644173-dell-micro-1u-rack-mount) | Well reviewed; M4 through-bolts; clear material advice | No keystone, no bricks |
| [simbaja, Lenovo Tiny 1U](https://www.thingiverse.com/thing:4769452) | Variant that bolts to steel Penn-Elcom ears | Single machine |
| [harebonse, Lenovo Tiny](https://makerworld.com/en/models/619346-lenovo-tiny-thinkcentre-19-rack-mount) | Accommodates the 135 W PSU; STEP file | Single machine |
| [Modular 19" system](https://www.printables.com/model/179524-modular-19-inch-rack-mounting-system) | Modular, pinned, bricks beside the PCs, Fusion source | Bricks beside halves the density; no keystone |
| [Mauker, modular blanks](https://makerworld.com/en/models/770165) | A genuine half-width module ecosystem with STEP files | No micro-PC module, no bricks |

## Lessons adopted

- **Face-down printing** is the community standard for printed ears. Adopted as
  reasoning, then made moot by steel ears (DECISIONS.md D7).
- **Metal in the joints:** through-bolts and nuts beat plastic threads (D9).
- **Steel ears** exist as an established option (D8).
- **Centre support** matters once racked (D10).
- **Retention:** a recurring complaint about tray designs was nothing holding the
  machine in; ours has a rear stop and front lip (D12, D13).

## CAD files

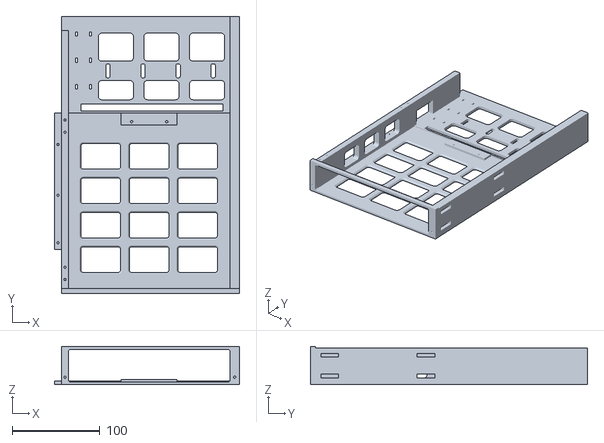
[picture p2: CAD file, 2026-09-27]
stl/tray_right.stl
211.0 x 316.0 x 43.7

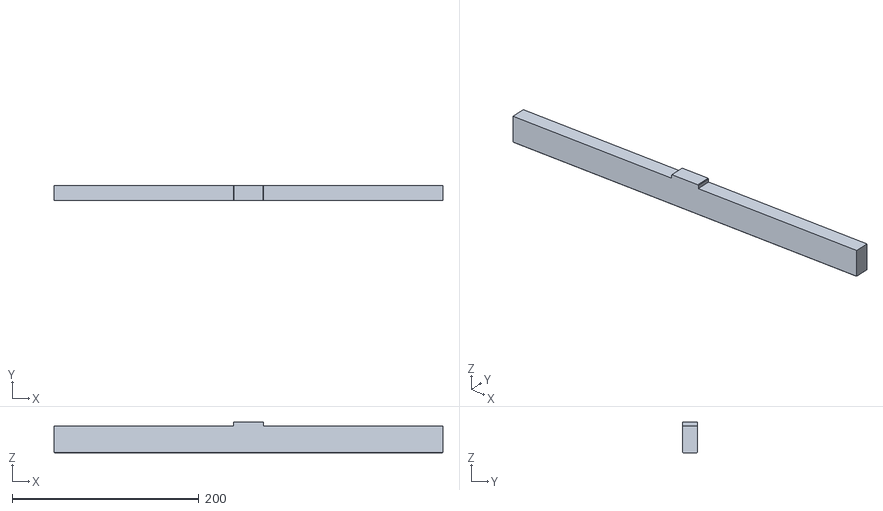
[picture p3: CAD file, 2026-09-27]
stl/rear_beam.stl
416.6 x 16.0 x 33.0

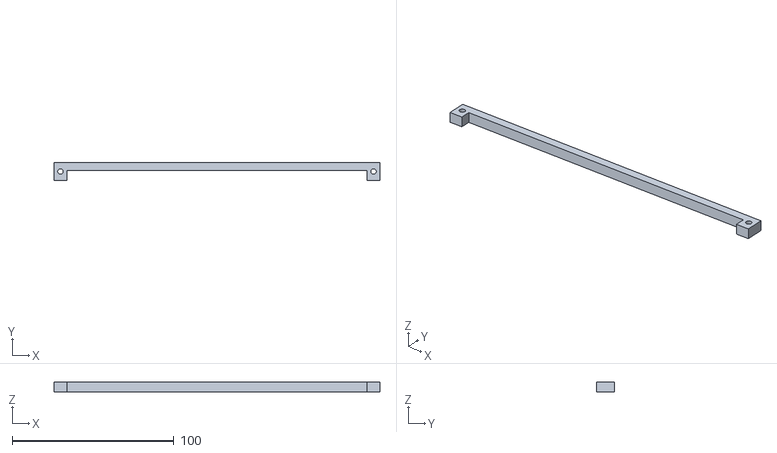
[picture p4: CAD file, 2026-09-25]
stl/front_lip.stl
201.5 x 11.0 x 6.00

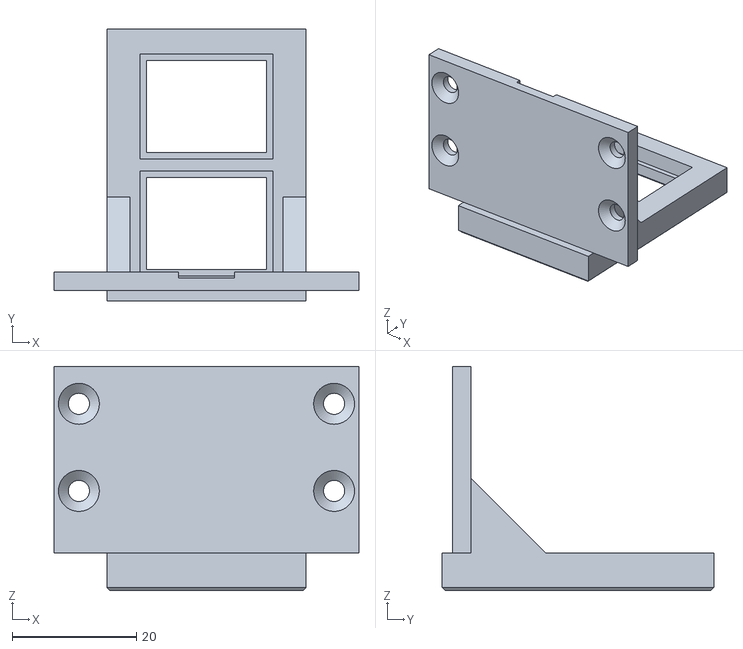
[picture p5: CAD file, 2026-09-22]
stl/keystone.stl
49.0 x 43.7 x 36.0

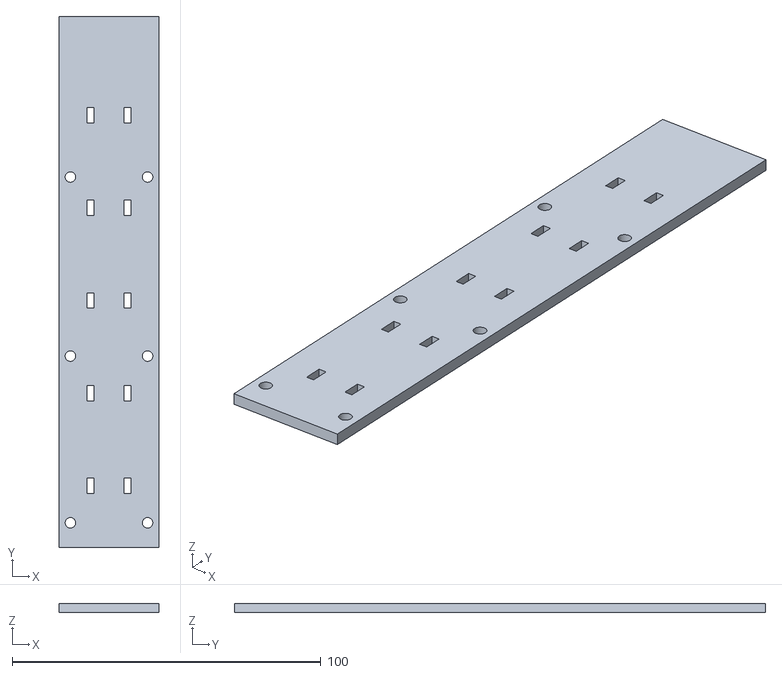
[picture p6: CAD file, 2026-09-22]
stl/cable_floor.stl
32.4 x 172.0 x 3.00

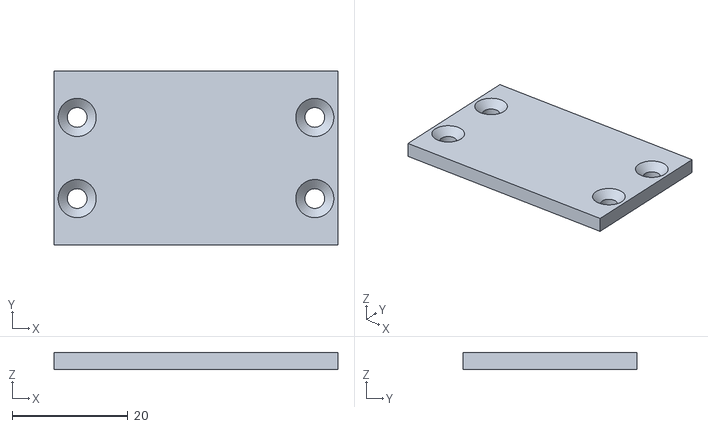
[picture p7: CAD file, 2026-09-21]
stl/tie_plate.stl
49.0 x 30.0 x 3.00

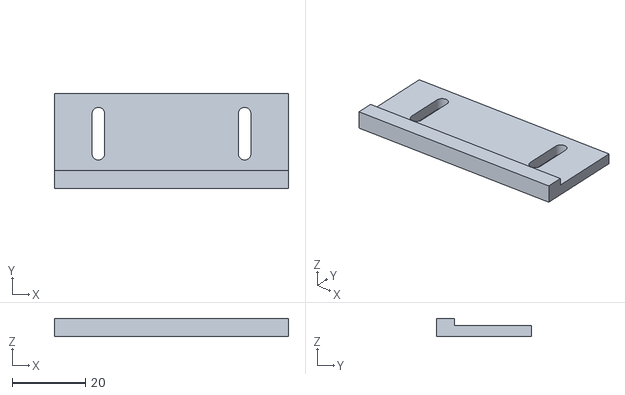
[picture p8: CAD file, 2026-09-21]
stl/rear_stop.stl
64.0 x 26.0 x 5.00

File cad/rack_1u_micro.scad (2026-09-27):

// =====================================================================
//  MODULAR 19" MICRO-PC RACK SYSTEM  —  v3
//  1U shelf: two 1-litre micro PCs, front-loading, stacked keystone bay,
//  power bricks in each tray's rear section.  Mounts on steel rack ears
//  (Penn-Elcom R1206/1U or equivalent) — no printed ear.
//
//  x = 0 at the left rail face, y = 0 at the rack face, z = 0 at the
//  bottom of the U.  Units: millimetres.
//
//  © 2026 Matt Miller and contributors.  Licence: CC BY-NC-SA 4.0
//  SPDX-License-Identifier: CC-BY-NC-SA-4.0
// =====================================================================

/* [Part to render] */
part = "tray_left"; // [tray_left,tray_right,keystone,front_lip,rear_stop,tie_plate,cable_floor,rear_beam,assembly]
show_devices = true;

/* [Rack + steel bracket] */
rack_u      = 1;
u_h         = 44.45;
panel_gap   = 0.8;
panel_t     = 6;
brk_h       = 43.8;    // bracket leg height
brk_row_z   = 9.4;     // lowest hole, up from bracket bottom edge
brk_row_dz  = 23.8;    // vertical spacing of the two hole rows
brk_col_dy  = 110;     // depth spacing of the two hole columns
brk_len     = 139.4;   // bracket web length
brk_t       = 1.5;     // bracket steel thickness
rack_open   = 450.85;  // measured clear width between the front rails (#5)
rack_margin = 2.0;     // minimum clearance per side, across the ear-bolt heads (D28)

/* [Device] */
dev_w = 182;
dev_d = 183;
dev_h = 36;
fit   = 1;
dev_depths = [178, 183]; // machines the rear stop must reach: Dell 7060 Micro, Lenovo Tiny (D32)

/* [Structure] */
wall_o   = 11;    // outer wall — carries the M4 ear-bolt pockets
wall_i   = 8;     // inner wall — carries the keystone, tie-plate and lip screws
key_w    = 33;    // narrowest the braced, rotated jacks allow (D28)
floor_t  = 3;
tray_d   = 206;
pad_t    = 3;
flange_t = 3;
flange_l = 30;

/* [M4 ear bolts] */
nut_s    = 7.0;   // M4 square nut (DIN 557) across flats; the pocket is sized to it
nut_m    = 3.2;   // nut thickness
nut_clr  = 0.4;   // pocket clearance over nut_s; the diagonal (9.9) can't turn in it
skin_t   = 7.3;   // solid outer skin the bolt passes through
bolt_slot = 4.5;  // M4 clearance slot height
ear_c0   = 22;    // first bracket hole column at mid-travel, from the rack face
ear_travel = 16;  // fore-aft adjustment of the shelf against the bracket

/* [Keystone] */
ks_w  = 19.3;     // aperture, rotated 90 deg (stacked pair)
ks_h  = 14.8;
ks_gap = 4;
ks_wall = 2.8;
ks_clr = 0.5;     // side clearance of the keystone panel in the gap between trays
ks_chamfer = 0.5; // 45-deg chamfer on the face-down edges: eats elephant's foot (D30)
ks_relief_d = 1.0;  // relief in the flange underside over the upper rear video plug,
ks_relief_w = 9;    // so a slim (16 mm) HDMI head clears it — D26

/* [Braces] — D27 */
ks_brace   = 12;   // keystone panel-to-flange braces, leg length
ks_brace_w = 3.7;  // each sits in the strip outside the jacks, clear of latch travel

/* [Floor vents] */
vent_chamfer = 1.5; // 45-deg top-edge chamfer so rubber feet ride out of the vents (D32)

/* [Rear stop] */
stop_h = 8;       // top of the stop face above the tray floor; the stop touches
                  // only this band of the rear face, so any port layout clears it

/* [Cable floor] */
cf_y0   = 50;     // starts behind the lower rear video plug's head (slim HDMI, D26)
cf_ext  = 16;     // overhang past the tray rear, into the gap between brick bays
cf_t    = 3;
ledge_w = 8;      // ledge on each inner wall that carries the cable floor (2.65 mm
                  // of plastic either side of its M3 pilot, D30)
ledge_h = 4;      // also the zip-tie clearance under the floor

/* [Brick bay] — the rear section of each tray (D34) */
bb_front = 12;    // open plenum slot at the front of the bay
bb_depth = 82;
bb_rear  = 16;    // rear strip of the bay, where the rear beam sits (D34)
lead_y   = [4, 39]; // window in the inner wall for the video leads, from the bay front
lead_h   = 20;

/* [Rear beam] — one piece across both trays' rear strips, glued in (D34) */
rb_clr  = 0.2;    // glue gap at each end, against the outer walls
rb_foot = 0.6;    // chamfers that keep elephant's foot out of the glue joints
bb_clear = 25;    // bay depth kept clear behind the machines' rear plugs; the
                  // bricks' front edges sit here, located by the strap row

/* [Bricks] — calipered 2026-09-25 (D33); L x W x T, laid crosswise so W runs
   front to back and T stands up */
bricks   = [[107, 46, 29],   // Lenovo 65 W slim
            [128, 66, 23]];  // Dell 90 W
strap_w  = 16;               // velcro strap width; the slots and grooves fit it
strap_y  = 48;               // one slot row, centred on the narrower brick
strap_x  = [30, 70, 110, 150]; // two loops per brick, (30,70) and (110,150)
strap_loop = 40;             // slot pitch of a loop; the groove runs between them
vent_rows = [[15, 22], [59, 32]]; // bay-y start and height of each vent row:
                                  // ahead of and behind the strap row

/* [Hardware] */
d_pilot = 2.7;
d_free  = 3.4;
d_csk   = 6.6;

/* [Hidden] */
csk_h = (d_csk - d_free)/2;   // 90-degree countersink, truncated at the clearance hole
$fn = 40;
eps = 0.01;

// ---------------------- derived ----------------------
panel_h = rack_u*u_h - panel_gap;
bay_w   = dev_w + 2*fit;
body_w  = 2*bay_w + 2*wall_o + 2*wall_i + key_w;
seam_l  = wall_o + bay_w + wall_i;
seam_r  = body_w - seam_l;
bay_x0  = wall_o;
bay_cx  = bay_x0 + bay_w/2;
wall_ho = 42;                       // outer wall height
wall_hi = floor_t + dev_h;          // inner wall height = device top
open_z0 = floor_t;
open_z1 = floor_t + dev_h + 1.0;
brk_z   = [for (r=[0,1]) (u_h-brk_h)/2 + brk_row_z + r*brk_row_dz];
scr_y   = [panel_t+10, panel_t+24];
tie_y   = [tray_d-22, tray_d-8];
ret_y   = tray_d-10;                 // stop reaches 175.5-186.5 mm deep machines (D32)
ret_w   = 64;
pad_y0  = tray_d-14;
lip_h     = 5;                          // bar height across the opening
lip_t     = 6;                          // 6 deep: stiff to handle; M3 x 12 screws (D32)
lip_tab_h = 11;                         // taller tabs over the two wall strips
lip_tab_w = 8;
lip_scr_x = [wall_o/2, seam_l-wall_i/2];// tray x of the two lip screws
lip_edge  = wall_i/2;                   // hole centre to lip end, both ends
lip_x0    = lip_scr_x[0] - lip_edge;
lip_len   = seam_l - lip_x0;            // symmetric: same part fits either tray
lip_scr_z = floor_t + lip_tab_h/2;
bb_d    = bb_front + bb_depth + bb_rear;
cf_w    = key_w - 0.6;
cf_len  = tray_d + cf_ext - cf_y0;
cf_scr_y = [58, 112, 170];          // clear of the keystone flange and tie plate

module rr(w,h,r=2) { offset(r=r) square([w-2*r,h-2*r],center=true); }
module yprism(x,z,len) { translate([x,-eps,z]) rotate([-90,0,0]) linear_extrude(len) children(); }

// =====================================================================
//  TRAY
// =====================================================================
// One pocket per bracket hole, open to the bay: a square nut slides in from
// inside before the PC does, the bolt comes in from outside through the slot.
// The pocket is nut-height, so the nut's 9.9 mm diagonal can't turn in it; it
// only slides fore-aft with the travel. Every roof is a short bridge. (D29)
ear_y_min = ear_c0 - ear_travel/2 - (nut_s+nut_clr)/2;   // front edge of the front pockets
module ear_pockets() {
  for (z = brk_z, c = [0,1]) {
    y0 = ear_c0 + c*brk_col_dy - ear_travel/2;
    translate([-1, y0-bolt_slot/2, z-bolt_slot/2])
      cube([skin_t+1+eps, ear_travel+bolt_slot, bolt_slot]);            // bolt slot
    translate([skin_t, y0-(nut_s+nut_clr)/2, z-(nut_s+nut_clr)/2])
      cube([wall_o-skin_t+1, ear_travel+nut_s+nut_clr, nut_s+nut_clr]); // square nut
  }
}

// Vent cell (i,j) in 2D; grow > 0 enlarges it (the top-edge chamfer, and the tests).
vent_n = [3, 4];
module vent_cell(i, j, grow=0) {
  rib=10;
  x0=bay_x0+14; x1=bay_x0+bay_w-14;
  y0=panel_t+18; y1=panel_t+dev_d-18;
  cw=((x1-x0)-(vent_n[0]-1)*rib)/vent_n[0];  ch=((y1-y0)-(vent_n[1]-1)*rib)/vent_n[1];
  translate([x0+i*(cw+rib)+cw/2, y0+j*(ch+rib)+ch/2]) rr(cw+2*grow, ch+2*grow, 3+grow);
}
module floor_vents() {
  for (i=[0:vent_n[0]-1], j=[0:vent_n[1]-1]) {
    translate([0,0,-eps]) linear_extrude(floor_t+2*eps) vent_cell(i,j);
    hull() {                                    // chamfer, per cell: a machine's feet
      translate([0,0,floor_t-vent_chamfer]) linear_extrude(eps) vent_cell(i,j);  // ride
      translate([0,0,floor_t]) linear_extrude(eps) vent_cell(i,j,vent_chamfer);  // out
    }
  }
}

module inner_wall_vents() {
  for (i=[0:2])
    translate([seam_l-wall_i/2, panel_t+55+i*42+15, wall_hi/2-1])
      rotate([0,90,0]) linear_extrude(wall_i+14, center=true) rr(22,30,4);
}

module tray_left() { tray_front(); translate([0, tray_d, 0]) brick_bay(); }  // one part (D34)
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

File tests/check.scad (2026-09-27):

// Geometry checks. Run via tests/run.sh, not directly.
// Each test renders an intersection; the runner measures its volume.
include <../cad/rack_1u_micro.scad>
test = "";

// Machines sit where the front lip holds them: front face at y = 0 (D32).
module dev(x0){ translate([x0+fit,0,floor_t]) cube([dev_w,dev_d,dev_h]); }
module devL(){ dev(bay_x0); }
module devR(){ dev(body_w-bay_x0-bay_w); }
module corrL(){ hull(){ devL(); translate([0,-260,0]) devL(); } }   // pull-out path
module corrR(){ hull(){ devR(); translate([0,-260,0]) devR(); } }
lipLx = lip_x0;  lipRx = body_w - lip_x0 - lip_len;
module lipL(){ translate([lipLx,-lip_t,floor_t]) front_lip(); }
module lipR(){ translate([lipRx,-lip_t,floor_t]) front_lip(); }
module stopL(d=dev_d){ translate([bay_cx-ret_w/2,d,floor_t+pad_t]) rear_stop(); }
module stopR(d=dev_d){ translate([body_w-bay_cx-ret_w/2,d,floor_t+pad_t]) rear_stop(); }
module tieP(){ translate([seam_l-wall_i,tray_d-30,wall_hi]) tie_plate(); }
module beamP(){ translate([0,tray_d+bb_d-bb_rear,0]) rear_beam(); }
module bbL(){ translate([0,tray_d,0]) brick_bay(); }                      // rear section of
module bbR(){ translate([body_w,tray_d,0]) mirror([1,0,0]) brick_bay(); } // each tray (D34)
// thin rods down each lip hole *as placed*: they must pass cleanly into the pilots
module lipRods(x0){ for(h=[lip_edge, lip_len-lip_edge])
  translate([x0+h,0.5,lip_scr_z]) rotate([-90,0,0]) cylinder(d=2.0,h=5); }
// voids modelled as solids, so void-vs-void contact can be measured
module outerPilot(){ translate([lip_scr_x[0],-eps,lip_scr_z]) rotate([-90,0,0]) cylinder(d=d_pilot,h=ear_y_min-1); }
module openingAboveLip(){ translate([bay_x0,-10,floor_t+lip_h]) cube([bay_w,10,dev_h]); }
// M4 x 12 button head on the 1.5 mm steel web: shank x -1.5..10.5, square nut
// (DIN 557) skin_t..skin_t+nut_m. 'ins' sweeps the nut in from the bay, which is
// the only way it can get there. Checked at both ends of travel, all 4 holes.
module xcyl(d,x0,x1,fn=40){ translate([x0,0,0]) rotate([0,90,0]) cylinder(d=d,h=x1-x0,$fn=fn); }
module sqnut(x0) translate([x0, -nut_s/2, -nut_s/2]) cube([nut_m, nut_s, nut_s]);
module m4hw(ins){
  xcyl(4,-brk_t,-brk_t+12);
  if (ins) hull(){ sqnut(skin_t); sqnut(wall_o+2); } else sqnut(skin_t);
}
module m4all(ins,past=0){ for(z=brk_z, c=[0,1], e=[-1,1])
  translate([0, ear_c0+c*brk_col_dy+e*(ear_travel/2+past), z]) m4hw(ins); }

if (test=="tray_keystone_L")  intersection(){ tray_left();  keystone(); }
if (test=="tray_keystone_R")  intersection(){ tray_right(); keystone(); }
if (test=="tray_lip_L")       intersection(){ tray_left();  lipL(); }
if (test=="tray_lip_R")       intersection(){ tray_right(); lipR(); }
if (test=="tray_stop_L")      intersection(){ tray_left();  stopL(); }
if (test=="tray_stop_R")      intersection(){ tray_right(); stopR(); }
if (test=="trays_tie")        intersection(){ union(){ tray_left(); tray_right(); } tieP(); }
if (test=="tray_device_L")    intersection(){ tray_left();  devL(); }
if (test=="tray_device_R")    intersection(){ tray_right(); devR(); }
if (test=="tray_tray")        intersection(){ tray_left();  tray_right(); }
if (test=="keystone_tie")     intersection(){ keystone();   tieP(); }
if (test=="pullout_L")        intersection(){ tray_left();  corrL(); }
if (test=="pullout_R")        intersection(){ tray_right(); corrR(); }
if (test=="lip_blocks_L")     intersection(){ lipL(); corrL(); }
if (test=="lip_blocks_R")     intersection(){ lipR(); corrR(); }
if (test=="lip_holes_L")      intersection(){ tray_left();  lipRods(lipLx); }
if (test=="lip_holes_R")      intersection(){ tray_right(); lipRods(lipRx); }
if (test=="pilot_vs_pocket")  intersection(){ outerPilot(); ear_pockets(); }
if (test=="lip_clear_of_face")intersection(){ lipL(); openingAboveLip(); }
if (test=="m4_hw_seated")     intersection(){ tray_left(); m4all(false); }
if (test=="m4_hw_insertable") intersection(){ tray_left(); m4all(true); }
if (test=="m4_past_travel")   intersection(){ tray_left(); m4all(false, 4); } // must hit
// the nut can't spin: its full turning circle (the 9.9 mm diagonal) must hit wall
module nutSpin() for(z=brk_z, c=[0,1], e=[-1,1])
  translate([skin_t, ear_c0+c*brk_col_dy+e*ear_travel/2, z]) rotate([0,90,0]) cylinder(d=nut_s*sqrt(2), h=nut_m);
if (test=="m4_nut_cannot_spin") intersection(){ tray_left(); nutSpin(); }
// cable floor, rear stop band, zip-tie clearance
module cfP(){ translate([seam_l+0.3,cf_y0,ledge_h]) cable_floor(); }
module cfRods(){ for(x=[seam_l+ledge_w/2, seam_r-ledge_w/2], y=cf_scr_y)      // M3 x 6 cores
  translate([x,y,ledge_h+cf_t-6]) cylinder(d=2.6,h=6); }
module zipVoid(){ translate([seam_l+ledge_w+0.5,cf_y0,0]) cube([key_w-2*ledge_w-1,tray_d-cf_y0,ledge_h]); }
module rearFaceAbove(){ translate([bay_x0+fit,dev_d,floor_t+stop_h]) cube([dev_w,1,dev_h-stop_h]); }
module rearFaceBand(){  translate([bay_x0+fit,dev_d,floor_t]) cube([dev_w,1,stop_h]); }
if (test=="tray_cf")          intersection(){ union(){ tray_left(); tray_right(); } cfP(); }
if (test=="keystone_cf")      intersection(){ keystone(); cfP(); }
if (test=="tie_cf")           intersection(){ tieP(); cfP(); }
if (test=="bricks_cf")        intersection(){ union(){ bbL(); bbR(); } cfP(); }
if (test=="cf_holes")         intersection(){ union(){ tray_left(); tray_right(); cfP(); } cfRods(); }
if (test=="ziptie_void")      intersection(){ union(){ tray_left(); tray_right(); keystone(); cfP(); } zipVoid(); }
if (test=="rear_face_open_L") intersection(){ stopL(); rearFaceAbove(); }
if (test=="stop_meets_face_L")intersection(){ stopL(); rearFaceBand(); }
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

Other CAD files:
stl/tray_left.stl

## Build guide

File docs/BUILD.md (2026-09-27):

# Modular 19" Micro-PC Rack System — build guide

A 1U shelf for two 1-litre micro PCs, front-loading, with a stacked keystone bay for
video pass-through and a rear bay for the power bricks, printed as part of each tray. Mounts on **steel rack
ears** — there is no printed ear, so no plastic in the critical load path.

Bays accept up to **182 × 183 × 36 mm**: Lenovo ThinkCentre/ThinkStation Tiny, Dell
OptiPlex Micro, HP EliteDesk Mini. Overall depth ~316 mm. Overall width 439 mm, or
446.4 mm across the ear-bolt heads with the steel ears fitted: allow at least 450.4 mm
clear between the front rails (2 mm per side; D28).

Source: `cad/rack_1u_micro.scad`. Pre-exported binary meshes in `stl/`; regenerate with `bash build.sh`.

---

## Parts

| Part | Qty | Footprint |
|---|---|---|
| `tray_left` / `tray_right` | 1 each | 211 × 316 × 44 mm, brick bay included (D34) |
| `keystone` | 1 | 49 × 44 × 36 mm |
| `rear_stop` | 2 | 64 × 26 × 5 mm |
| `front_lip` | 2 | 202 × 11 × 6 mm — symmetric, same part both sides |
| `tie_plate` | 1 | 49 × 30 × 3 mm |
| `cable_floor` | 1 | 32 × 172 × 3 mm |
| `rear_beam` | 1 | 417 × 16 × 33 mm — glued into the back of both trays (D34) |

One rear stop fits every machine. It's a low curb that touches only the bottom 8 mm of
the rear face, so it doesn't care about case height or where the ports are.

Each tray is 211 × 316 mm, so it needs a bed at least 320 mm on one axis. The rear beam is
417 mm long and prints top-down along the diagonal of a 325 × 320 area, with ~8 mm to
spare each side (`tests/run.sh` checks this). The STLs are exported
in print orientation. In that orientation two features need support: the strip above
each tray's PC opening, and the keystone flange's two wings. Everything else prints
without (`tests/run.sh` checks this; D31). Roughly 910 cm³ / 690 g of filament.

**PETG, ASA or PC-blend — not PLA.** Root bending stress is only 0.73 MPa, so this is
about creep in a warm rack over months, not about strength.

## Bill of materials

**Rack mounting**
- 2 × steel 1U rack ear brackets (Penn-Elcom R1206/1U or equivalent, ~$5.50 each)
- 8 × M4 × 12 button head — anything taller than a button head fouls the rail
- 8 × M4 **square** nuts (7.0 mm across flats, 3.2 thick — standard DIN 557). No washers.
- 4 × rack screws + cage nuts for the brackets themselves

**Assembly**
- 4 × M3 × 16 countersunk — keystone module
- 4 × M3 × 16 countersunk — tie plate
- 4 × M3 × 8 pan — rear stops
- 6 × M3 × 6 pan — cable floor to ledges
- 4 × M3 × 12 pan head — front lips
- All M3 threads directly into 2.7 mm printed pilots. No inserts anywhere.
- Structural adhesive suited to your filament, for the rear beam

**Other**
- 2 × keystone couplers, female-female: HDMI or mini-DisplayPort, one per machine
- 2 × video cables, PC rear port to the back of the jack. **The plug heads must be
  small.** The jacks are rotated, so each rear plug stands on its long edge, and the two
  sit on 18.8 mm centres. Use one of:
  - slim-head HDMI, passive, head ≤ 16 mm wide (e.g. Monoprice Ultra Slim, Cable Matters
    Ultra Thin);
  - mini-DP couplers with DP ↔ mini-DP cables (the machines keep their full-size DP ports).

  Standard-head HDMI or DP plugs (~21 mm) collide with each other and with the keystone
  flange. A standard HDMI plug fits only in the **lower** jack, with a mini-DP above it,
  and then the cable floor has to start at ~85–90 mm (`cf_y0`). See D26.
- 4 × velcro straps, 16 mm wide and at least 250 mm long, for the power bricks (two
  loops per brick)
- Small zip ties (up to 4 mm wide) for the DC and video leads

## The ear bolts

Each outer wall has four pockets, one per bracket hole, at z = 9.7 and 33.5 mm to match
the bracket's two hole rows (9.4 mm up from the bracket's bottom edge, 23.8 mm apart) and
110 mm apart front to back. Each pocket opens into the bay: slide a square nut in from
inside, then bolt through the bracket's Ø4.8 hole from outside. An M4 × 12 lands flush
with the nut face and stops 0.5 mm short of the bay.

The bolt passes through a slot rather than a hole, giving ±8 mm of fore-aft travel. The
bracket's hole column position doesn't need to be exact, and you can slide the shelf to
set how far it sits proud of the rack face. The pocket is only 0.4 mm taller than the
nut, so the nut slides along the slot but can't turn: no tool needed on the inside.

Tighten **snug, not hard.** The nut bears on the strips of plastic either side of the
slot, and those crush long before an M4 is at full torque. The joint doesn't need clamp
force: the shelf's weight is carried by the bolt shanks bearing on the slot edges.

## Assembly

Everything up to racking happens on the bench. Once the shelf is racked, the ear bolts,
the nuts, the rear-stop screws and the backs of the keystones can't be reached, because
the U above blocks access from the top.

1. Fit the keystone couplers first. Lay the keystone module face-down on a flat surface
   and press the couplers in until they click. Once installed, the panel hangs from its
   top edge only, so don't push couplers into it afterwards.
2. Slide a square nut into each of the four pockets in each tray's outer wall, from
   inside the bay, and bolt the steel ears on loosely.
3. Drop the keystone module between the two tray fronts; screw its top flange into both
   inner walls. Fit the tie plate at the back of the PC bays the same way.
4. Slide the cable floor in from the rear onto the two ledges between the trays and screw
   it down (6 screws, all reachable from above).
   Then, on a flat surface, glue the rear beam into the back of both trays: it sits on the
   floors between the outer walls, against the ends of the inner walls, and is glued to
   all three. Let it cure. From here the shelf is one unit.
5. Set the depth: slide the shelf along the bracket slots until its front sits where you
   want it relative to the ear legs, then tighten all eight M4s snug.
6. Set the rear stops: slide each machine in from the front, push its rear stop forward
   against the bottom of the rear face, tighten, then slide the machine back out.
7. Thread the four velcro straps first: each goes down through one slot of a pair, along
   the groove under the floor, and up through the other, so two loops wait in each bay.
   Bricks go in crosswise on top of them, mains-cord ends outboard, DC ends toward the
   centre. The strap row sets each brick's front edge ~25 mm back from the bay front,
   which keeps that space clear for the machines' rear plugs. Cinch the straps. Mains
   cords, like the machines' other rear cables, pass over the rear beam.
8. Plug the video leads into the backs of the couplers (reachable only from above), run
   them back along the cable floor and through the window in each tray's inner wall behind
   the machine, and zip-tie them to the slot pairs in the cable floor and the anchors along
   the inboard edge of each brick bay.
9. Rack the shelf empty.
10. Slide each machine in from the front, connect its rear cables, and fit the front lip.

## Servicing

To remove a machine:

1. From behind the rack, unplug its rear cables (power, video, network). The ports are
   about 130 mm into the shelf, past the brick, so it's a tight reach, but a rare one.
2. Undo the two front-lip screws, lift the lip off, and slide the machine out the front.

To refit, do the reverse: slide the machine in until it meets the rear stop, refit the
lip, and reconnect its cables from behind.

The shelf doesn't store service loops. These machines have no hot-swappable parts, so
there's no reason to pull one while it's running, and pulling a machine out with its
cables attached would need ~200 mm of slack per cable that the bay has no room for.

The rear stop stays put. It's a set-once adjustment, not a service item.

## Customising

```
openscad -o tray_left.stl -D 'part="tray_left"' cad/rack_1u_micro.scad
```

| Parameter | Default | Effect |
|---|---|---|
| `dev_w`, `dev_d`, `dev_h` | 182, 183, 36 | device envelope |
| `stop_h` | 8 | how far up the rear face the rear stop reaches |
| `dev_depths` | 178, 183 | machine depths the rear stop must reach (Dell 7060 Micro, Lenovo Tiny); the stop adjusts over 175.5–186.5 mm and `tests/run.sh` checks each |
| `vent_chamfer` | 1.5 | 45° chamfer on the floor vents' top edges so rubber feet ride out instead of catching |
| `cf_y0` | 50 | where the cable floor starts; the lower rear video plug's head has to clear it |
| `ks_relief_d`, `ks_relief_w` | 1.0, 9 | relief in the keystone flange underside over the upper rear plug |
| `ks_brace`, `ks_brace_w` | 12, 3.7 | keystone panel-to-flange braces; wider than 3.7 intrudes on latch travel |
| `bricks` | 107 × 46 × 29, 128 × 66 × 23 | the power bricks, L × W × T (Lenovo 65 W slim, Dell 90 W); `tests/run.sh` checks each fits the bay and sits under the strap band |
| `strap_y`, `bb_clear` | 48, 25 | the velcro slot row, and where it puts the bricks' front edges; move both for a much deeper brick |
| `brk_row_z`, `brk_row_dz` | 9.4, 23.8 | bracket hole rows — change these if your brackets measure differently |
| `wall_o` | 11 | outer wall; must stay thick enough to hold the ear-bolt pockets |
| `nut_s`, `nut_clr`, `skin_t` | 7.0, 0.4, 7.3 | square nut size, its pocket clearance (the nut's 9.9 mm diagonal must not fit), and the solid skin the bolt passes through |
| `ear_c0`, `ear_travel` | 22, 16 | first bracket hole column at mid-travel, and the fore-aft travel of the slots |
| `bb_depth`, `bb_rear` | 82, 16 | brick bay depth, and the strip behind it that the rear beam fills; the beam's depth is most of the shelf's stiffness (D34) |
| `rb_top` | 33 | rear beam top, set from the tallest entry in `bricks`; the rear is open above it for air and cables, and a taller beam is stiffer (D34) |
| `ks_gap` | 4 | vertical gap between the stacked keystone apertures |
| `key_w` | 33 | keystone column width; 33 is the narrowest the braced jacks allow (D28) |
| `ks_clr`, `ks_chamfer` | 0.5, 0.5 | keystone panel side clearance, and the chamfer on its face-down edges and apertures |
| `ledge_w` | 8 | cable-floor ledges; below ~8 the M3 pilot's inboard wall gets thin enough to split |
| `rack_open`, `rack_margin` | 450.85, 2.0 | measured rail opening and the clearance `tests/run.sh` enforces across the ear-bolt heads |

## Known limitations

- **Thermal:** both machines exhaust rearward toward the brick bay. There's a ~40 mm gap
  behind each machine (17 mm to the tray's rear edge plus the 25 mm kept clear at the
  front of the bay), an open vent grid under the bricks and an open rear, but two adapters sitting in
  a 1U exhaust stream is not a configuration I can promise runs cool. The bays are part of
  the trays (D34), so moving the bricks to their own U means a different shelf.
- The bays are laid out for the two calipered bricks (Lenovo 65 W slim 107 × 46 × 29 mm,
  Dell 90 W 128 × 66 × 23; ~11 mm of headroom over the taller one). A different adapter
  needs to be 31–77 mm front to back to sit under the strap band and inside the bay, and
  under ~37 mm tall with a strap over it. Add it to `bricks` and `tests/run.sh` checks both.
- Verified against the bracket drawing, not against a bracket in hand. Check the 23.8 mm
  row spacing (`brk_row_dz`) and the bend-to-first-hole distance (`ear_c0`) with calipers
  before printing both trays; each is a one-parameter fix.
- Front-rail mounting only. The numbers say that's fine — 0.4 mm of creep deflection over
  a warm year — but an asymmetrically loaded shelf will still twist slightly, which is
  what the tie plate and rear beam are there to resist.

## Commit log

2026-09-21 Initial commit: 1U micro-PC rack shelf, design v3.1
    3D-printable 19" rack shelf for two 1L micro PCs (Lenovo Tiny + Dell
    OptiPlex Micro): parametric OpenSCAD source, canonicalised STLs, a
    CAD interference/alignment test suite, and build/decision/prior-art docs.
    Provenance: v1 through v3.1 were designed over several iterations in
    Claude Cowork before any git history existed; docs/DECISIONS.md records
    that evolution. This commit captures the v3.1 state, and development
    continues from here with Claude Code.
    [brick_bay.stl, check.scad, front_lip.stl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]
2026-09-21 Licence the project under CC BY-NC-SA 4.0
    Add the full licence text, a Licence section in the README, and decision
    D20. Replaces the undecided CC-BY-4.0 note in the OpenSCAD source header.
    [rack_1u_micro.scad]
2026-09-21 Docs: state mounting and thermal constraints in general form
    Requirement 8 is front-rail-only mounting, not a particular rack type;
    D14 and D16 now give the reasoning and the design assumptions (duty
    cycle, ventilated rack, ambient) a builder needs to judge fit. Add a
    gitignored local/ directory for private setup notes.
2026-09-21 Root the brick bay's inner mounting tab to the floor
    Both front mounting tabs started at z=8. The outer tab overlaps the
    outer lip (12 mm) beneath it; the inner edge is the open cable-run side
    with no lip, so the inner tab floated 4 mm above the 4 mm floor. brick_bay
    exported as two separate bodies, sliced as an unsupported island, and one
    of the two bolts holding each bay to its tray went through it.
    Both tabs now run from the floor. The outer tab is unchanged in the union.
    brick_bay: 2 shells -> 1, +128 mm3 (exactly the 8 x 4 x 4 mm gap).
    New test bb_tab_rooted_L requires the space under the inner tab to be
    solid. It fails on v3.1 and passes here; all other checks still pass.
    Logged as D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
    [brick_bay.stl, check.scad, front_lip.stl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]
2026-09-21 Replace the ear nut channels with per-bolt pockets
    The M4 nut channels could not be loaded. They were sealed at both ends
    (y 8-165 in a wall running 6-206, so "slide the nuts in from the rear"
    met 41 mm of solid wall) and the only opening was the 4.8 mm bolt slot,
    which a 7 mm nut passes only lying flat, with no room in the 4 mm pocket
    to stand it up. Sweeping the m4_nut_fits nut out of its seat towards the
    bay, outside, rear or front hits wall every time. Each channel roof was
    also a 157 mm unsupported bridge.
    Four pockets per tray instead, one per bracket hole, open to the bay.
    Washer and nut drop in from inside; the bolt enters from outside through
    a slot that keeps +/-8 mm of fore-aft t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
    [check.scad, rack_1u_micro.scad, tray_left.stl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]
2026-09-21 Open the rear of the bays and give the video leads a route
    Rear stop: the hook's web was a solid 64 x 33 mm plate flush against the
    middle third of each machine's rear face, where the ports and exhaust
    are, and it depended on dev_h (hence the Lenovo variant). It is now a
    low curb touching only the bottom stop_h (8 mm) of the rear face. One
    part fits every machine; rear_stop_lenovo_34.5mm is removed from the
    build.
    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
    [brick_bay.stl, cable_floor.stl, check.scad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]
2026-09-21 Fix fastener lengths, keystone clearance and assembly order
    Rear stop: the BOM's M3 x 10 through the 3 mm foot came out 1 mm through
    the underside of the tray. Now M3 x 8, and the pilot starts at z=0.6 so
    the flat tip clears the pilot bottom rather than meeting it.
    Keystone: the panel was 36.0 mm in a 36.0 mm gap between the tray
    panels. Now 35.4 mm (ks_clr = 0.3 per side, matching the cable floor).
    Assembly: tightening the ear bolts and setting the rear stops after
    racking can't be done with the U above populated. The nuts and stop
    screws are reached from above, and the bolt heads sit between bracket
    and rail. That work now happens on the bench, along with fitting the
    couplers (first, pan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
    [check.scad, keystone.stl, rack_1u_micro.scad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]
2026-09-21 Pin OpenSCAD to 2026.09.18
    Different OpenSCAD versions tessellate curves differently, and
    canon_stl.py only makes identical triangles byte-identical, so builders
    on different versions rewrite every curved STL on every build. Pin to
    2026.09.18, the owner's version and the current Homebrew
    openscad@snapshot.
    build.sh records OPENSCAD_VERSION and warns (does not fail) when the
    running version differs; a mismatched build is still geometrically
    correct, just noisy in git. README documents the pin and how to install
    it. Logged as D25.
    The merged review PRs were built on 2026.06.12. Rebuilt here on
    2026.09.18, three STLs change (brick_bay, tray_left, tray_right) with
    identical volume and bounding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
    [brick_bay.stl, tray_left.stl, tray_right.stl]
2026-09-21 Clear the rear video plugs: flange relief, cable floor moved back
    The rotated, stacked jacks put each rear plug on its long edge, 18.8 mm
    apart, between the keystone flange (underside z=39, back to y=36) and
    the cable floor. Modelled as blocks at coupler depths of 24 and 32 mm,
    slim HDMI heads (16 x 6.6 x 14) overlapped the flange by 18 / 6 mm3 and
    the cable floor by 34 mm3 at the deeper depth. Standard heads
    (~21 mm) collide under every option considered.
    A 1 mm relief in the flange underside over the upper plug (ks_relief_d,
    ks_relief_w = 9) gives 0.8 mm clearance there and keeps 2.8 mm between
    the plugs, where shrinking ks_gap to 3 would give 0.3 / 1.8 mm and halve
    the plastic between th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
    [cable_floor.stl, check.scad, keystone.stl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]
2026-09-21 Document the servicing procedure decided in #7
    BUILD.md's Servicing section still called rear-cable slack storage an
    open question. #7 settled it: a machine's rear cables are unplugged
    from behind the rack before it slides out the front. The section now
    gives that procedure and the refit, and says why the shelf doesn't
    store service loops (~200 mm per cable needed; ~8-27 mm free behind
    each machine; no hot-swap parts, so pulling one live isn't needed).
    D11 gains a dated note recording the decision, edited in place rather
    than appended so this can merge independently of the open PRs.
    Docs only; no geometry or tests change.
2026-09-21 Correct the cable floor length in the parts table
    cf_y0 moved 44 -> 50 in the previous commit, so the cable floor is
    172 mm long, not 178.
2026-09-21 Brace the keystone panel and the brick bay mounting tabs
    Keystone: the panel hangs from a 35.4 x 3 mm joint with the flange,
    which is a layer boundary as printed. A 30 N push on the lower jack
    (plugging in a monitor at the front) gives ~16 MPa there. Two 12 mm
    braces between panel back and flange underside, in the 3.7 mm strips
    at the panel edges outside the jacks' latch travel, take that to
    ~2.2 MPa.
    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
    [brick_bay.stl, check.scad, keystone.stl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]
2026-09-21 Narrow the keystone column to 33 mm for rack clearance
    Across the M4 button heads (body + 2 x 1.5 mm web + 2 x 2.2 mm head) the
    shelf was 449.4 mm. Matt measured the rack's clear width between the
    front rails at 450.85 mm (#5): 0.7 mm per side, about a tape's own
    accuracy before print tolerance or web flatness.
    Four ways to take 3 mm out were run against the full suite. Only
    narrowing the keystone column (key_w 36 -> 33) passes everything; taking
    it from bay fit or inner walls breaks pullout and/or lip_clear_of_face.
    Now 439 mm body, 446.4 mm across the heads, 2.2 mm per side. Keystone,
    tie plate and cable floor follow key_w. Latch access beside each
    keystone brace drops from ~4.3 to ~2.85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
    [cable_floor.stl, check.scad, keystone.stl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]
2026-09-22 Ear bolts: square nut in a nut-height pocket, no washer
    D22's pocket was sized to a 9 mm washer, so it was taller than the hex
    nut's 8.1 mm corners: the nut spun freely, held only by a fingertip (a
    spanner can't get around it in the pocket). #15 also points out the
    washer had 0.3 mm of clearance, which layer quantisation and roof sag
    can close.
    A square M4 nut (DIN 557) in a pocket 0.4 mm over its 7 mm flats can
    turn only ~2.5 deg before it locks, and still slides fore-aft with the
    +/-8 mm travel. In the washer-height pocket it would turn 23-37 deg
    before jamming corner-first. Dropping the washer frees 0.8 mm, so the
    skin goes 6.5 -> 7.3 mm; M4 x 12 still lands flush with the nut face.
    Bea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
    [check.scad, rack_1u_micro.scad, tray_left.stl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]
2026-09-22 Printability fixes from the H2D review (#15)
    - Cable-floor ledges 6 -> 8 mm: the centred M3 pilot left 1.65 mm of
    plastic inboard, likely to split; now 2.65 mm each side. Zip-tie slot
    pairs move from +/-8 to +/-6 to fit the narrower void.
    - Plenum slot (y 2-10) and front velcro slots (y 10-26) touched at
    y=10, leaving the bay's bearing front edge as thin ribs. Front velcro
    row moves to y 20.5: 2.5 mm ribs to the plenum and the vent grid.
    - Velcro strap path recessed: each slot pair joined by a 16 x 2 mm
    underside groove, so straps no longer stand below the shelf.
    - Keystone panel prints face-down: 0.5 mm 45-deg chamfer on its
    face-down perimeter and apertures (ks_chamfer), ks_clr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
    [brick_bay.stl, cable_floor.stl, check.scad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]
2026-09-22 Test each part for unsupported overhangs in print orientation (#15)
    Every existing check is solid-against-solid in the assembly, so nothing
    could see how a part prints: that's how the keystone flange wings and
    v3's floating brick-bay tab got through.
    The export transforms move into a printed(p) module shared by the
    render dispatch and the tests (STLs byte-identical). Each part is
    sliced every 0.4 mm in print orientation; material not within 45 deg of
    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
    [check.scad, rack_1u_micro.scad]
2026-09-22 Docs cleanup: correct stale statements, re-render the preview
    README
    - preview.png re-rendered from the current assembly (it still showed
    v3.1: tall rear hooks, no cable floor, nut channels).
    - Status points at the review fixes (D21-D31).
    - Layout no longer calls BUILD.md "print settings".
    - Open items: coupler choice is slim-head HDMI or mini-DP (not "DP or
    HDMI"); the bracket caliper check adds the bend-to-first-hole
    distance behind ear_c0; new item for the machines' rubber-foot
    positions (#15).
    BUILD.md
    - Replaces "supports from the build plate are enough" (wrong: the
    support stands on the panel's own lower strip) with a geometric note:
    in the exported orientation the tray st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
2026-09-23 Rear stop reaches the Dell; stiffer front lip; chamfered floor vents
    Rear stop: with the front lip fitted a machine's front sits at y=0, so
    the stop must reach the machine's depth. Its slots covered only
    179.5-190.5 mm, missing the 178 mm Dell 7060 Micro (~1.5 mm of rattle).
    The tests modelled machines 6 mm back and couldn't see it. Stop pilots
    and pad move 4 mm forward (ret_y = tray_d - 10): 175.5-186.5 mm. The
    test envelope and assembly now put machines against the lip; new
    dev_depths parameter lists the machines and stop_reaches_* checks each
    (the Dell check fails at the old position).
    Front lip: 3 -> 6 mm deep, ~8x stiffer in bending and much stiffer in
    torsion; same height, so it cover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
    [check.scad, front_lip.stl, rack_1u_micro.scad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]
2026-09-25 Bricks calipered; one strap row centred on them (D33)
    Both power bricks were measured and are smaller than D15 assumed in
    every axis: Lenovo 65 W slim 107 x 46 x 29 (was 112 x 51 x 35), Dell
    90 W 128 x 66 x 23 (was 130 x 70 x 28). They're now in the source as
    `bricks` so the tests can use them.
    Headroom over the Lenovo is ~11 mm, not ~5.5; the "room for a strap,
    nothing more" warning goes.
    The velcro slot rows at y 20.5 and 93 needed a brick >= 59 mm deep to
    sit under both bands. With the brick's front edge 25 mm back, as
    BUILD.md asks, the front band overlapped the Lenovo by 3.5 mm and the
    rear band not at all. Replaced by one row at y 48 (`strap_y`), inside
    both bricks' footprints with >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
    [brick_bay.stl, check.scad, rack_1u_micro.scad]
2026-09-27 One-piece trays and a glued rear beam; centre sag ~11 mm -> ~3 (D34)
    Each tray now prints with its brick bay (211 x 316 mm), and one
    417 x 16 x 33 mm rear beam is glued in across both: on the floors,
    between the outer walls, against the inner walls' ends. Continuous
    across the centre, it stops the seam hinging. Its top is level with the
    tallest brick, so the rear stays open above it for exhaust and cables.
    Worst centre sag (grillage model, solid plastic): 11.4 -> 2.9 mm
    short-term, ~25 -> ~6.5 mm after creep.
    brick_bay.stl, its bolts and the tab checks are gone; rear_beam.stl is
    new. Needs a 320 mm bed. Stacked on #22.
    [brick_bay.stl, check.scad, rack_1u_micro.scad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]
